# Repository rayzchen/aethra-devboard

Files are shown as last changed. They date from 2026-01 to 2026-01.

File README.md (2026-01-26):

# aethra-devboard
Custom devboard based on the RP2040 chip. Includes LiPo 3.7V battery charger and
power source selector, onboard neopixel LED, 16MB flash storage and 29 GPIO
pins.

## Schematic
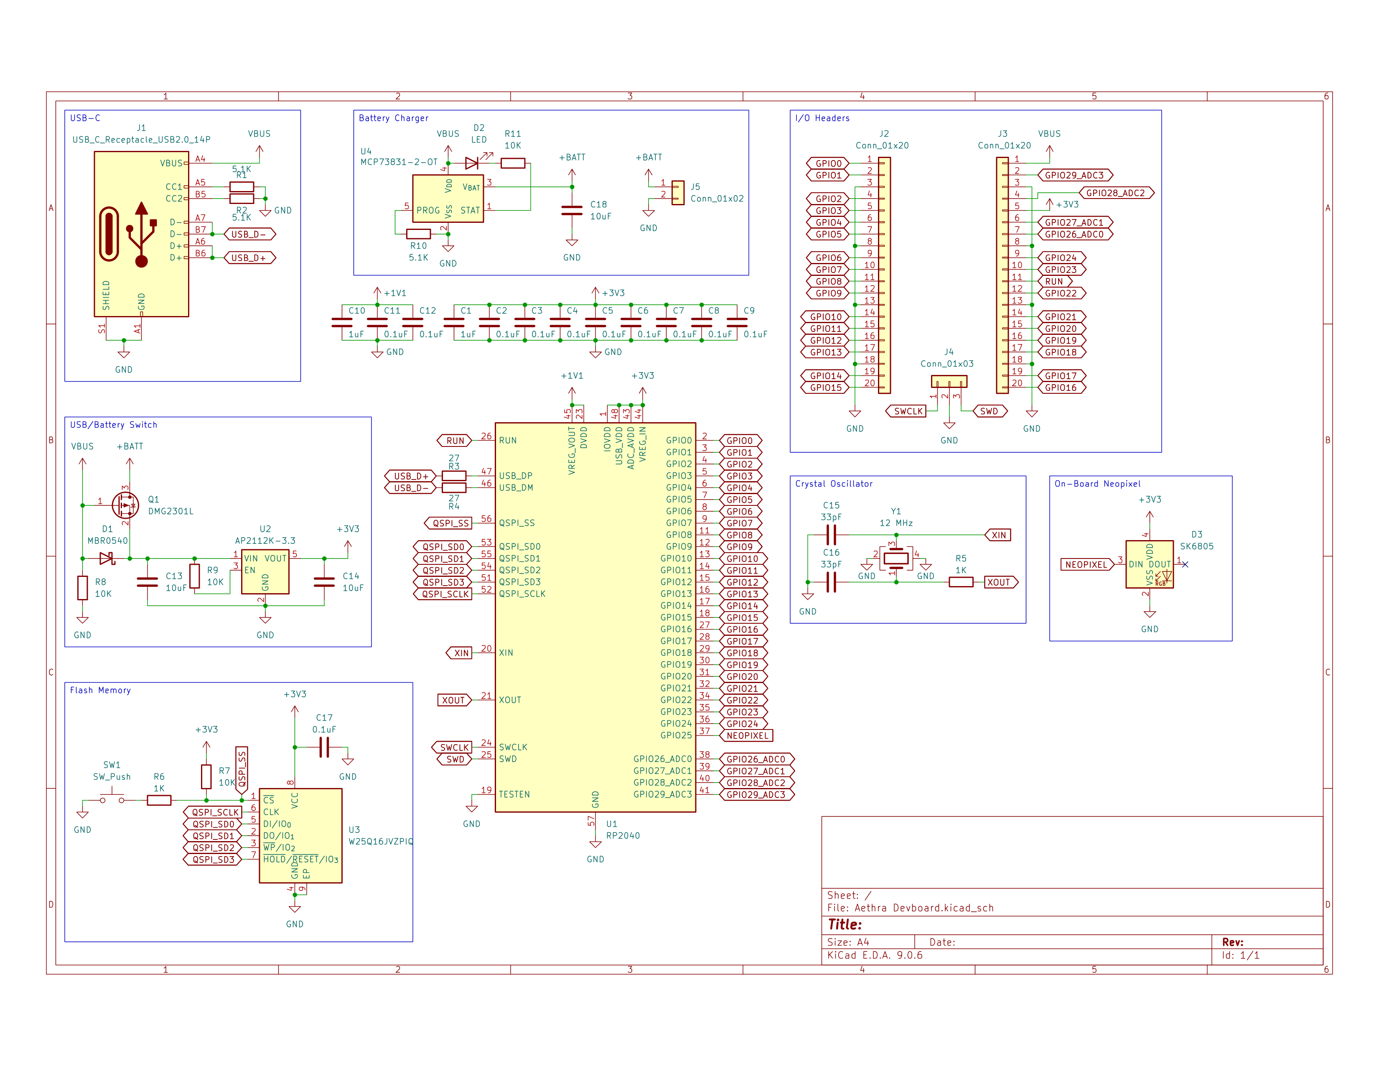
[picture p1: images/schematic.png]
Schematic diagram


## PCB
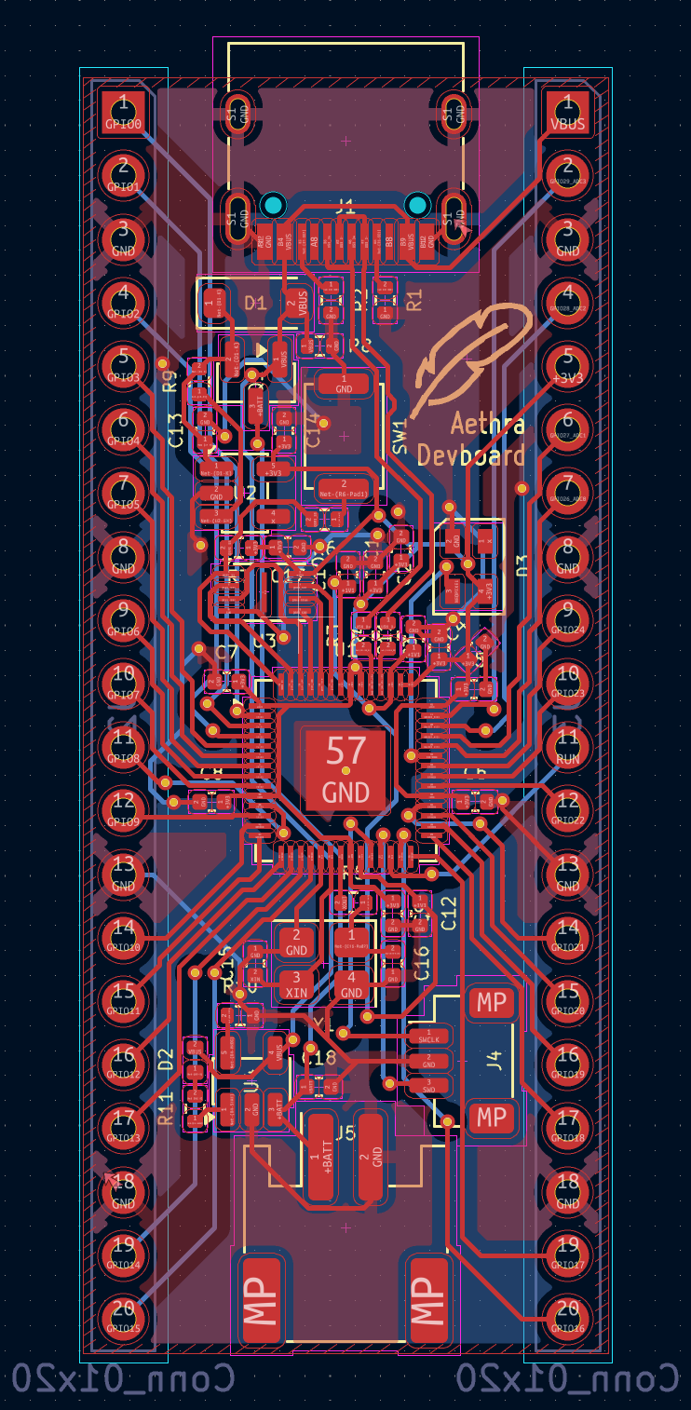
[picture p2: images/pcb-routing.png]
PCB routing


## BOM
|Comment |Footprint |LCSC Part No|Quantity|Link |Price/unit |Total |
|---|---|---|---|---|---|---|
|AP2112K-3.3 |SOT-23-5 |C23380830 |1 |https://www.lcsc.com/product-detail/C23380830.html |0.0975 |0.0975|
|RP2040 |QFN-56-1EP_7x7mm_P0.4mm_EP3.2x3.2mm |C2040 |1 |https://www.lcsc.com/product-detail/C2040.html |0.9577 |0.9577|
|33pF |C_0402_1005Metric |C1562 |2 |https://www.lcsc.com/product-detail/C1562.html |0.0011 |0.0022|
|0.1uF |C_0402_1005Metric |C1525 |11 |https://www.lcsc.com/product-detail/C1525.html |0.0013 |0.0143|
|10K |R_0402_1005Metric |C25744 |4 |https://www.lcsc.com/product-detail/C25744.html |0.0007 |0.0028|
|1uF |C_0402_1005Metric |C52923 |2 |https://www.lcsc.com/product-detail/C52923.html |0.0032 |0.0064|
|1K |R_0402_1005Metric |C11702 |2 |https://www.lcsc.com/product-detail/C11702.html |0.0006 |0.0012|
|Conn_01x02 |JST_PH_S2B-PH-SM4-TB_1x02-1MP_P2.00mm_Horizontal|C295747 |1 |https://www.lcsc.com/product-detail/C295747.html |0.1877 |0.1877|
|27 |R_0402_1005Metric |C138021 |2 |https://www.lcsc.com/product-detail/C138021.html |0.0008 |0.0016|
|12 MHz |Crystal_SMD_3225-4Pin_3.2x2.5mm |C9002 |1 |https://www.lcsc.com/product-detail/C9002.html |0.0681 |0.0681|
|W25Q16JVZPIQ |Winbond_USON-8-1EP_3x2mm_P0.5mm_EP0.2x1.6mm |C377853 |1 |https://www.lcsc.com/product-detail/C377853.html |1.0674 |1.0674|
|USB_C_Receptacle_USB2.0_14P|USB_C_Receptacle_HRO_TYPE-C-31-M-12 |C165948 |1 |https://www.lcsc.com/product-detail/C165948.html |0.1772 |0.1772|
|LED |LED_0402_1005Metric |C130719 |1 |https://www.lcsc.com/product-detail/C130719.html |0.0369 |0.0369|
|10uF |C_0402_1005Metric |C15525 |3 |https://www.lcsc.com/product-detail/C15525.html |0.005 |0.015 |
|Conn_01x03 |JST_SH_BM03B-SRSS-TB_1x03-1MP_P1.00mm_Vertical  |C160389 |1 |https://www.lcsc.com/product-detail/C160389.html |0.2576 |0.2576|
|DMG2301L |SOT-23 |C102619 |1 |https://www.lcsc.com/product-detail/C102619.html |0.07 |0.07  |
|5.1K |R_0402_1005Metric |C25905 |3 |https://www.lcsc.com/product-detail/C25905.html |0.0006 |0.0018|
|MCP73831-2-OT |SOT-23-5 |C424093 |1 |https://www.lcsc.com/product-detail/C424093.html |0.7226 |0.7226|
|MBR0540 |D_SOD-123 |C116159 |1 |https://www.lcsc.com/product-detail/C116159.html |0.0204 |0.0204|
|SW_Push |SW_Push_SPST_NO_Alps_SKRK |C720477 |1 |https://www.lcsc.com/product-detail/C720477.html |0.0444 |0.0444|
|Conn_01x20 |PinHeader_1x20_P2.54mm_Vertical | |2 |https://www.aliexpress.com/item/4001053521664.html |1.255 |2.51  |
|SK6805 |LED_SK6805_PLCC4_2.4x2.7mm_P1.3mm | |1 |https://www.aliexpress.com/item/1005008719791221.html|1.37 |1.37  |
| | | | | |Grand Total|7.6328|

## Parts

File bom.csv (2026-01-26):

Comment | Designator | Footprint | LCSC Part No | Quantity | Link | Price/unit | Total
AP2112K-3.3 | U2 | SOT-23-5 | C23380830 | 1 | https://www.lcsc.com/product-detail/C23380830.html | 0.0975 | 0.0975
RP2040 | U1 | QFN-56-1EP_7x7mm_P0.4mm_EP3.2x3.2mm | C2040 | 1 | https://www.lcsc.com/product-detail/C2040.html | 0.9577 | 0.9577
33pF | C15,C16 | C_0402_1005Metric | C1562 | 2 | https://www.lcsc.com/product-detail/C1562.html | 0.0011 | 0.0022
0.1uF | C6,C5,C3,C2,C11,C8,C17,C9,C12,C7,C4 | C_0402_1005Metric | C1525 | 11 | https://www.lcsc.com/product-detail/C1525.html | 0.0013 | 0.0143
10K | R9,R11,R8,R7 | R_0402_1005Metric | C25744 | 4 | https://www.lcsc.com/product-detail/C25744.html | 0.0007 | 0.0028
1uF | C1,C10 | C_0402_1005Metric | C52923 | 2 | https://www.lcsc.com/product-detail/C52923.html | 0.0032 | 0.0064
1K | R5,R6 | R_0402_1005Metric | C11702 | 2 | https://www.lcsc.com/product-detail/C11702.html | 0.0006 | 0.0012
Conn_01x02 | J5 | JST_PH_S2B-PH-SM4-TB_1x02-1MP_P2.00mm_Horizontal | C295747 | 1 | https://www.lcsc.com/product-detail/C295747.html | 0.1877 | 0.1877
27 | R3,R4 | R_0402_1005Metric | C138021 | 2 | https://www.lcsc.com/product-detail/C138021.html | 0.0008 | 0.0016
12 MHz | Y1 | Crystal_SMD_3225-4Pin_3.2x2.5mm | C9002 | 1 | https://www.lcsc.com/product-detail/C9002.html | 0.0681 | 0.0681
W25Q16JVZPIQ | U3 | Winbond_USON-8-1EP_3x2mm_P0.5mm_EP0.2x1.6mm | C377853 | 1 | https://www.lcsc.com/product-detail/C377853.html | 1.0674 | 1.0674
USB_C_Receptacle_USB2.0_14P | J1 | USB_C_Receptacle_HRO_TYPE-C-31-M-12 | C165948 | 1 | https://www.lcsc.com/product-detail/C165948.html | 0.1772 | 0.1772
LED | D2 | LED_0402_1005Metric | C130719 | 1 | https://www.lcsc.com/product-detail/C130719.html | 0.0369 | 0.0369
10uF | C14,C13,C18 | C_0402_1005Metric | C15525 | 3 | https://www.lcsc.com/product-detail/C15525.html | 0.005 | 0.015
Conn_01x03 | J4 | JST_SH_BM03B-SRSS-TB_1x03-1MP_P1.00mm_Vertical | C160389 | 1 | https://www.lcsc.com/product-detail/C160389.html | 0.2576 | 0.2576
DMG2301L | Q1 | SOT-23 | C102619 | 1 | https://www.lcsc.com/product-detail/C102619.html | 0.07 | 0.07
5.1K | R10,R1,R2 | R_0402_1005Metric | C25905 | 3 | https://www.lcsc.com/product-detail/C25905.html | 0.0006 | 0.0018
MCP73831-2-OT | U4 | SOT-23-5 | C424093 | 1 | https://www.lcsc.com/product-detail/C424093.html | 0.7226 | 0.7226
MBR0540 | D1 | D_SOD-123 | C116159 | 1 | https://www.lcsc.com/product-detail/C116159.html | 0.0204 | 0.0204
SW_Push | SW1 | SW_Push_SPST_NO_Alps_SKRK | C720477 | 1 | https://www.lcsc.com/product-detail/C720477.html | 0.0444 | 0.0444
Conn_01x20 | J2,J3 | PinHeader_1x20_P2.54mm_Vertical |  | 2 | https://www.aliexpress.com/item/4001053521664.html | 1.255 | 2.51
SK6805 | D3 | LED_SK6805_PLCC4_2.4x2.7mm_P1.3mm |  | 1 | https://www.aliexpress.com/item/1005008979678361.html | 1.37 | 1.37
 |  |  |  |  |  | Grand Total | 7.6328

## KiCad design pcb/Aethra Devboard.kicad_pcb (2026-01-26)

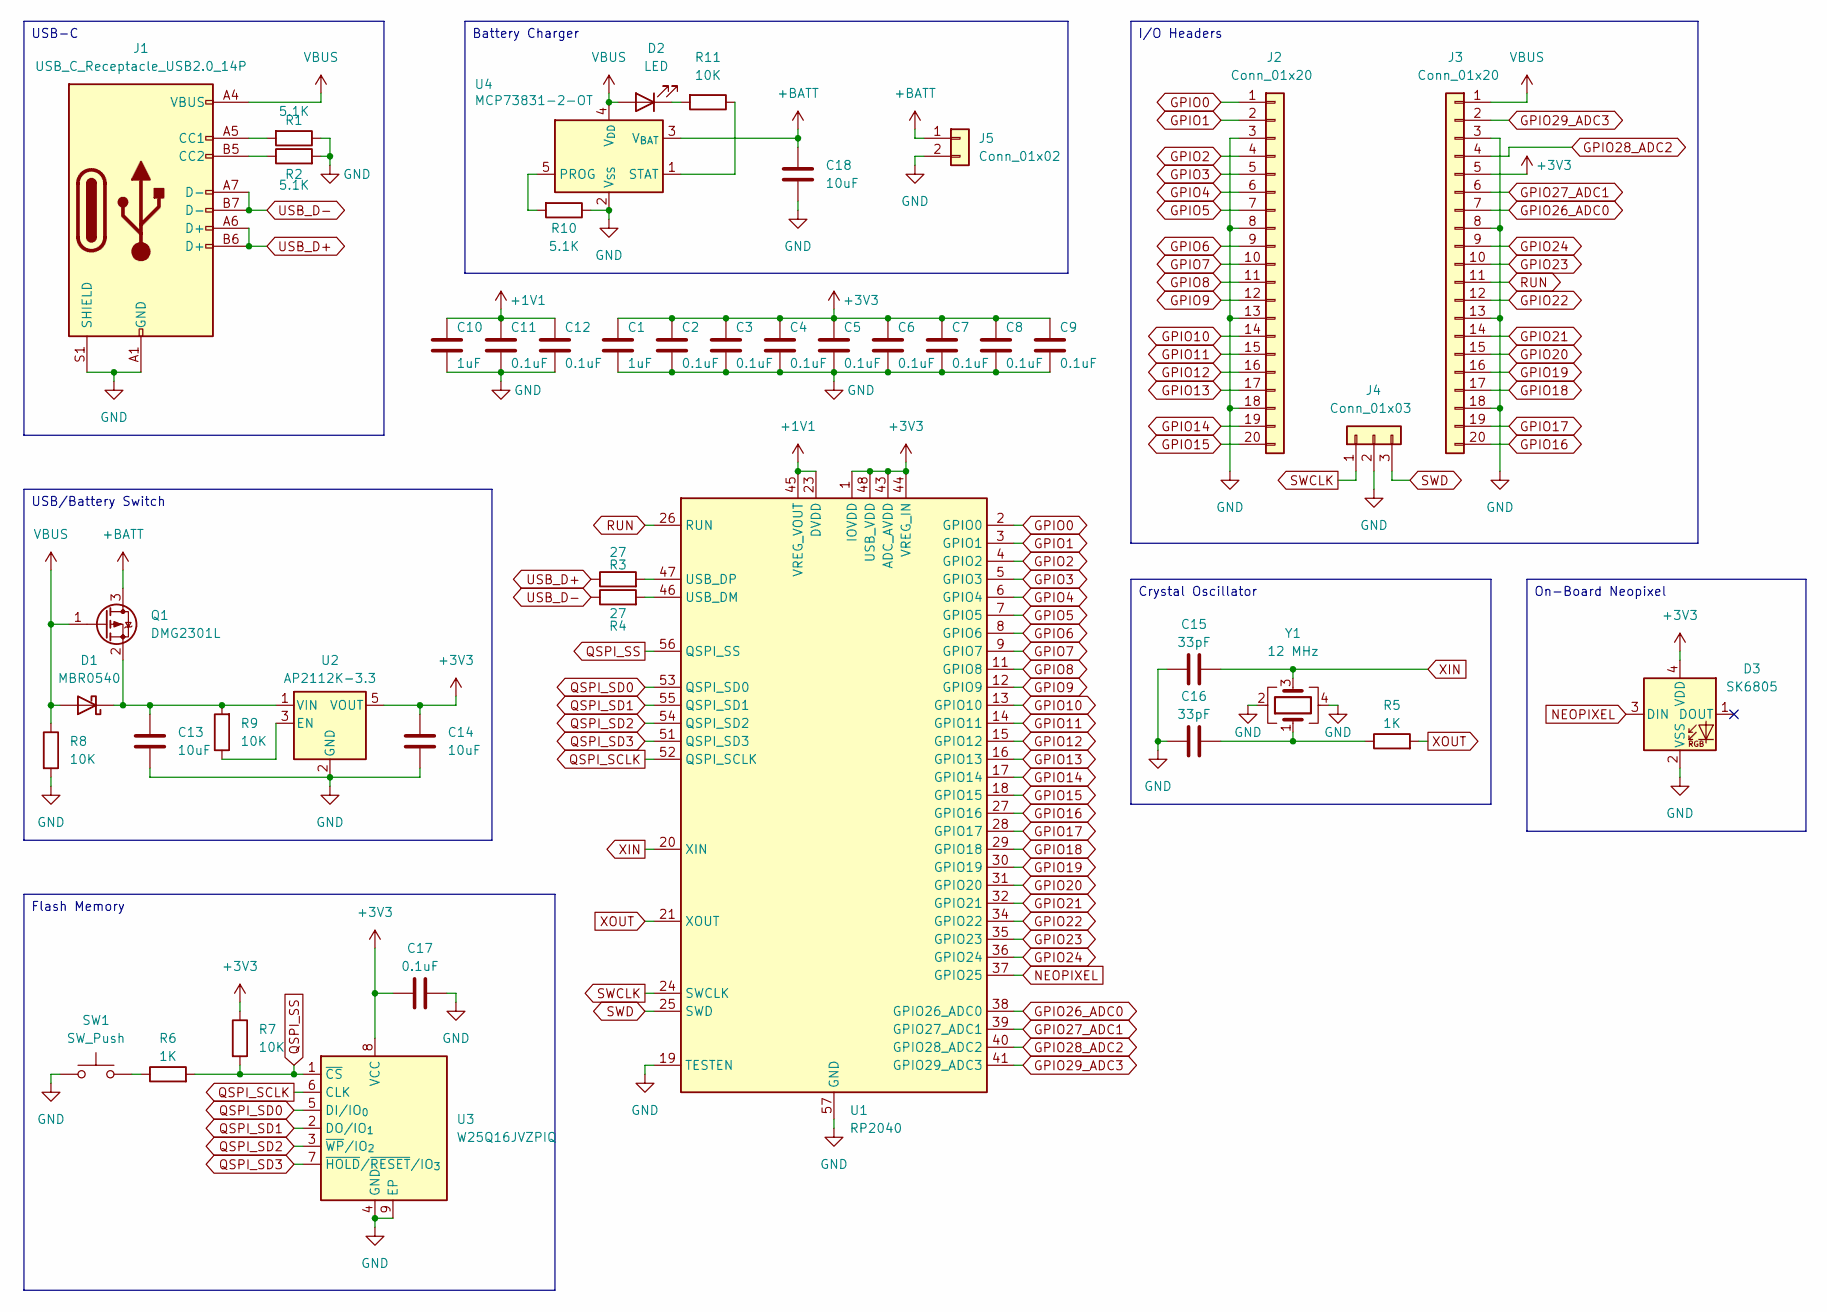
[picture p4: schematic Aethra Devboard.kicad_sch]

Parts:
C1, C10: 1uF; C_0402_1005Metric
C2, C3, C4, C5, C6, C7, C8, C9, C11, C12, C17: 0.1uF; C_0402_1005Metric
C13, C14, C18: 10uF; C_0402_1005Metric
C15, C16: 33pF; C_0402_1005Metric
D1: MBR0540; D_SOD-123
D2: LED; LED_0402_1005Metric
D3: SK6805; LED_SK6805_PLCC4_2.4x2.7mm_P1.3mm
J1: USB_C_Receptacle_USB2.0_14P; USB_C_Receptacle_HRO_TYPE-C-31-M-12
J2, J3: Conn_01x20; PinHeader_1x20_P2.54mm_Vertical
J4: Conn_01x03; JST_SH_BM03B-SRSS-TB_1x03-1MP_P1.00mm_Vertical
J5: Conn_01x02; JST_PH_S2B-PH-SM4-TB_1x02-1MP_P2.00mm_Horizontal
Q1: DMG2301L; SOT-23
R1, R2, R10: 5.1K; R_0402_1005Metric
R3, R4: 27; R_0402_1005Metric
R5, R6: 1K; R_0402_1005Metric
R7, R8, R9, R11: 10K; R_0402_1005Metric
SW1: SW_Push; SW_Push_SPST_NO_Alps_SKRK
U1: RP2040; QFN-56-1EP_7x7mm_P0.4mm_EP3.2x3.2mm
U2: AP2112K-3.3; SOT-23-5
U3: W25Q16JVZPIQ; Winbond_USON-8-1EP_3x2mm_P0.5mm_EP0.2x1.6mm
U4: MCP73831-2-OT; SOT-23-5
Y1: 12 MHz; Crystal_SMD_3225-4Pin_3.2x2.5mm

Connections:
+1V1: C10.1, C11.1, C12.1, U1.23 (DVDD), U1.45 (VREG_VOUT), U1.50 (DVDD)
+3V3: C1.1, C2.1, C3.1, C4.1, C5.1, C6.1, C7.1, C8.1, C9.1, C14.1, C17.1, D3.4 (VDD), J3.5, R7.1, U1.1 (IOVDD), U1.10 (IOVDD), U1.22 (IOVDD), U1.33 (IOVDD), U1.42 (IOVDD), U1.43 (ADC_AVDD), U1.44 (VREG_IN), U1.48 (USB_VDD), U1.49 (IOVDD), U2.5 (VOUT), U3.8 (VCC)
+BATT: C18.1, J5.1, Q1.3 (D), U4.3 (V_{BAT})
GND: C1.2, C2.2, C3.2, C4.2, C5.2, C6.2, C7.2, C8.2, C9.2, C10.2, C11.2, C12.2, C13.2, C14.2, C15.1, C16.1, C17.2, C18.2, D3.2 (VSS), J1.A1 (GND), J1.A12 (GND), J1.B1 (GND), J1.B12 (GND), J1.S1 (SHIELD), J2.3, J2.8, J2.13, J2.18, J3.3, J3.8, J3.13, J3.18, J4.2, J5.2, R1.1, R2.2, R8.2, R10.1, SW1.1, U1.19 (TESTEN), U1.57 (GND), U2.2 (GND), U3.4 (GND), U3.9 (EP), U4.2 (V_{SS}), Y1.2, Y1.4
GPIO0: J2.1, U1.2 (GPIO0)
GPIO1: J2.2, U1.3 (GPIO1)
GPIO2: J2.4, U1.4 (GPIO2)
GPIO3: J2.5, U1.5 (GPIO3)
GPIO4: J2.6, U1.6 (GPIO4)
GPIO5: J2.7, U1.7 (GPIO5)
GPIO6: J2.9, U1.8 (GPIO6)
GPIO7: J2.10, U1.9 (GPIO7)
GPIO8: J2.11, U1.11 (GPIO8)
GPIO9: J2.12, U1.12 (GPIO9)
GPIO10: J2.14, U1.13 (GPIO10)
GPIO11: J2.15, U1.14 (GPIO11)
GPIO12: J2.16, U1.15 (GPIO12)
GPIO13: J2.17, U1.16 (GPIO13)
GPIO14: J2.19, U1.17 (GPIO14)
GPIO15: J2.20, U1.18 (GPIO15)
GPIO16: J3.20, U1.27 (GPIO16)
GPIO17: J3.19, U1.28 (GPIO17)
GPIO18: J3.17, U1.29 (GPIO18)
GPIO19: J3.16, U1.30 (GPIO19)
GPIO20: J3.15, U1.31 (GPIO20)
GPIO21: J3.14, U1.32 (GPIO21)
GPIO22: J3.12, U1.34 (GPIO22)
GPIO23: J3.10, U1.35 (GPIO23)
GPIO24: J3.9, U1.36 (GPIO24)
GPIO26_ADC0: J3.7, U1.38 (GPIO26_ADC0)
GPIO27_ADC1: J3.6, U1.39 (GPIO27_ADC1)
GPIO28_ADC2: J3.4, U1.40 (GPIO28_ADC2)
GPIO29_ADC3: J3.2, U1.41 (GPIO29_ADC3)
NEOPIXEL: D3.3 (DIN), U1.37 (GPIO25)
unnamed: C16.2, R5.1, Y1.1
unnamed: C13.1, D1.1 (K), Q1.2 (S), R9.2, U2.1 (VIN)
unnamed: D2.1 (K), R11.2
unnamed: J1.A5 (CC1), R1.2
unnamed: J1.B5 (CC2), R2.1
unnamed: R6.1, SW1.2
unnamed: R4.2, U1.46 (USB_DM)
unnamed: R3.2, U1.47 (USB_DP)
unnamed: R9.1, U2.3 (EN)
unnamed: R10.2, U4.5 (PROG)
unnamed: R11.1, U4.1 (STAT)
QSPI_SCLK: U1.52 (QSPI_SCLK), U3.6 (CLK)
QSPI_SD0: U1.53 (QSPI_SD0), U3.5 (DI/IO_{0})
QSPI_SD1: U1.55 (QSPI_SD1), U3.2 (DO/IO_{1})
QSPI_SD2: U1.54 (QSPI_SD2), U3.3 (~WP/IO_{2})
QSPI_SD3: U1.51 (QSPI_SD3), U3.7 (~HOLD/~RESET/IO_{3})
QSPI_SS: R6.2, R7.2, U1.56 (QSPI_SS), U3.1 (~CS)
RUN: J3.11, U1.26 (RUN)
SWCLK: J4.1, U1.24 (SWCLK)
SWD: J4.3, U1.25 (SWD)
USB_D+: J1.A6 (D+), J1.B6 (D+), R3.1
USB_D-: J1.A7 (D-), J1.B7 (D-), R4.1
VBUS: D1.2 (A), D2.2 (A), J1.A4 (VBUS), J1.A9 (VBUS), J1.B4 (VBUS), J1.B9 (VBUS), J3.1, Q1.1 (G), R8.1, U4.4 (V_{DD})
XIN: C15.2, U1.20 (XIN), Y1.3
XOUT: R5.2, U1.21 (XOUT)

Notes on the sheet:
USB/Battery Switch
I/O Headers
Crystal Oscillator
Battery Charger
Flash Memory
USB-C
On-Board Neopixel

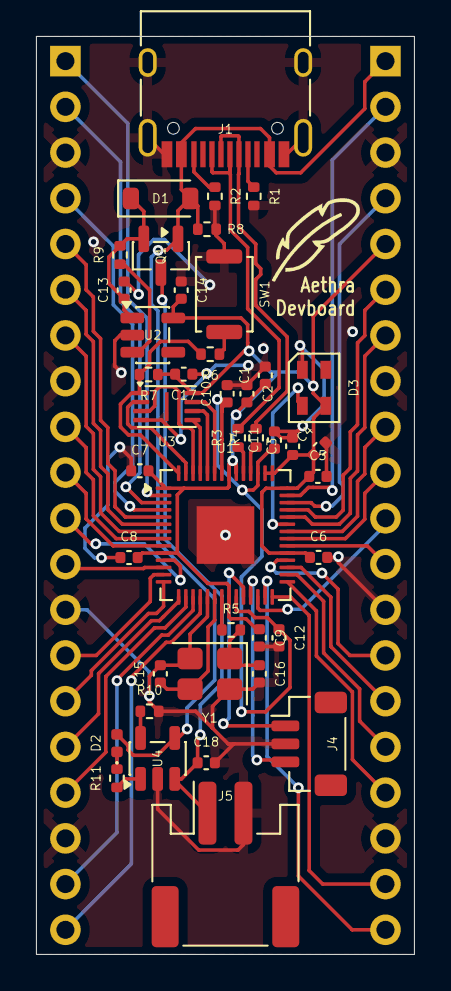
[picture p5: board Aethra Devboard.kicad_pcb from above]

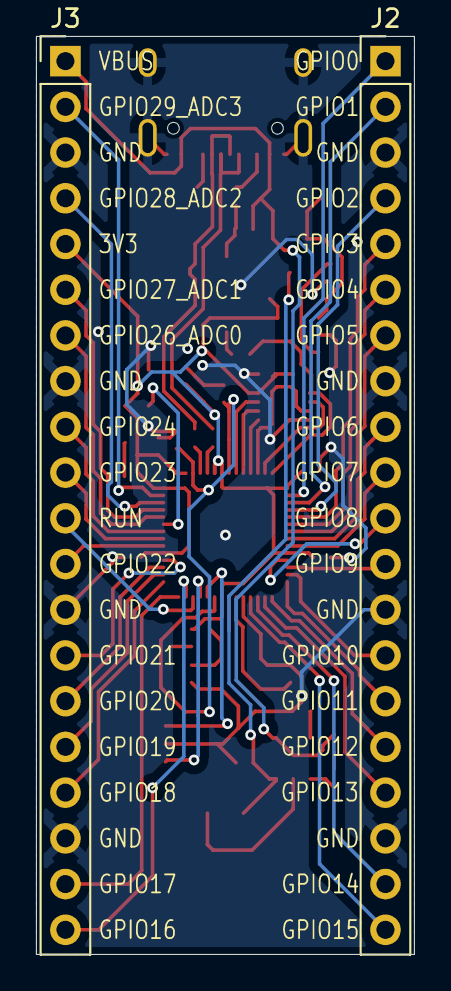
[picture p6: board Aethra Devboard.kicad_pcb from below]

Board: 2 copper layers, 21.0 x 51.0 mm, 44 parts (2 on the bottom side), 59 nets.

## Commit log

2026-01-22 First draft of schematic
    [Aethra Devboard.kicad_sch]
2026-01-24 Move kicad files to correct location
    [Aethra Devboard.kicad_sch]
2026-01-25 Add footprints to components
    [Aethra Devboard.kicad_sch]
2026-01-25 Start routing of PCB
    [Aethra Devboard.kicad_pcb]
2026-01-25 Finish routing PCB
    [Aethra Devboard.kicad_pcb, Aethra Devboard.kicad_sch]
2026-01-25 Add 3d models to viewer
    [Aethra Devboard.kicad_pcb]
2026-01-25 Add pinouts and icon to silkscreen
    [Aethra Devboard.kicad_pcb]
2026-01-25 Add BOM
    [bom.csv]
2026-01-26 Reroute PCB
    [Aethra Devboard.kicad_pcb]
2026-01-26 Correct BOM
    [bom.csv]
